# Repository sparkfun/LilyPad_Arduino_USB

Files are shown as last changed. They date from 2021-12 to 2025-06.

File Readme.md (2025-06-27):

LilyPad Arduino USB
===================

[LilyPad Arduino USB  
*LilyPad Arduino USB (DEV-11990)*](https://www.sparkfun.com/products/11190)

The LilyPad Arduino USB is a sewable Arduino compatible board with a built-in LiPo battery charger. It connects via microUSB cable to your computer, which means that, unlike regular LilyPad boards, it needs no external hardware to be programmed. 

As of Arduino release 1.0.2, the LilyPad Arduino USB is supported as a native board- no additional files needed!

Firmware was compiled in WinAVR-20100110.  
Hardware was developed in EAGLE 6.3.0.

License Information
-------------------
The hardware design is released under [CC-SA v3 license](http://creativecommons.org/licenses/by-sa/3.0/us/).

The firmware is released under a modified beerware license, allowing for the purchase of any libation, alcoholic or non.

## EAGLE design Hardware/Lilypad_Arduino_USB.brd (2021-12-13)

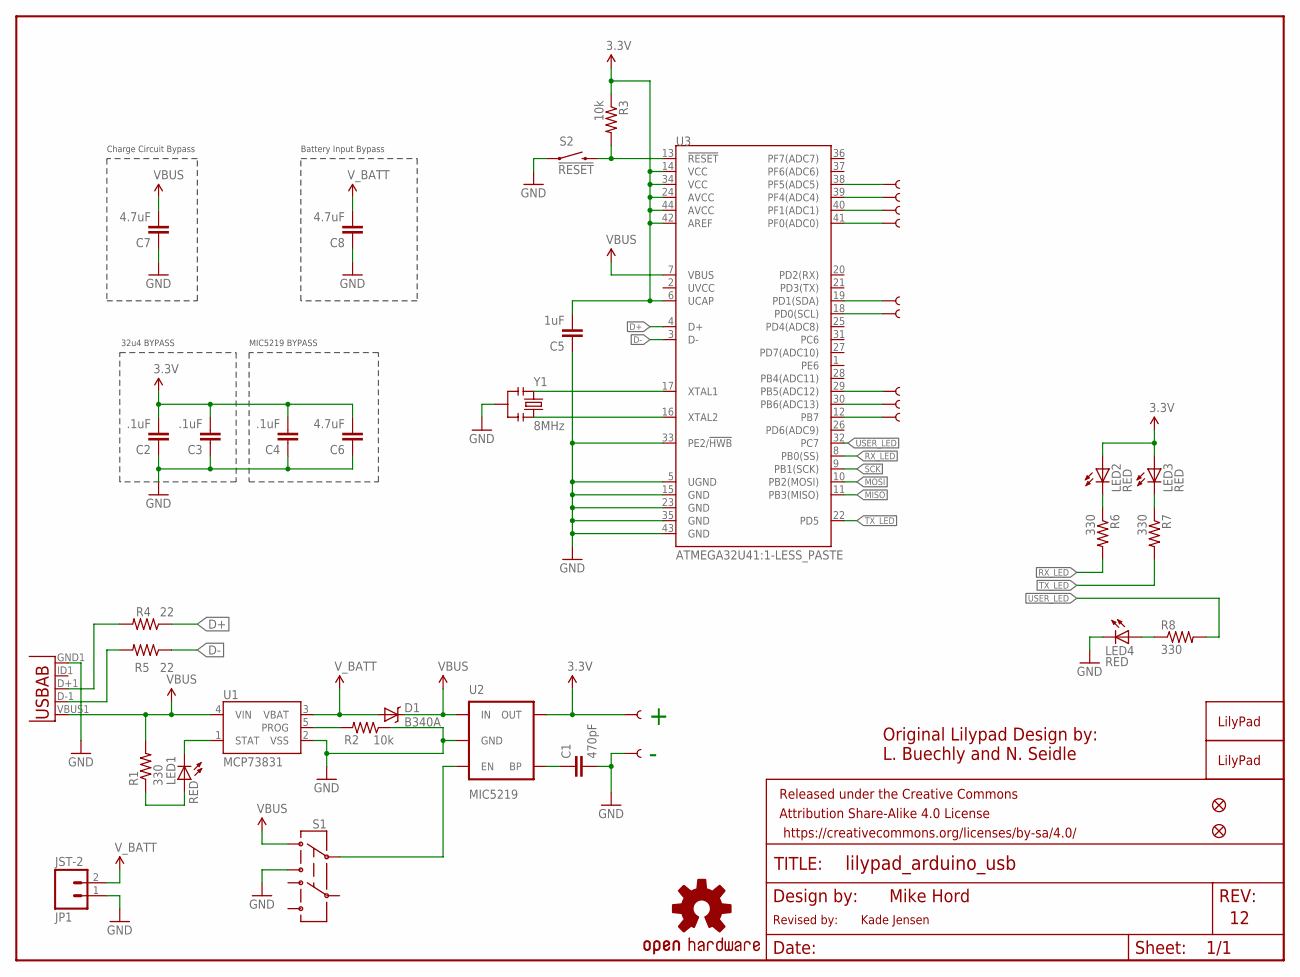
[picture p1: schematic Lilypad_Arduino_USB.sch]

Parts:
+: SEWTAP9; PETAL-LONG-1-2SIDE
-: SEWTAP9; PETAL-LONG-1-2SIDE
A2, A3, A4, A5: SEWTAP9; PETAL-LONG-1-2SIDE
C1: 470pF; 0603-CAP
C2, C3, C4: .1uF; 0603-CAP
C5: 1uF; 0603-CAP
C6: 4.7uF; 0603-CAP
C7, C8: 4.7uF; 1206
D1: B340A; SMA-DIODE
D5, D6, D9, D10, D11: SEWTAP9; PETAL-LONG-1-2SIDE
FRAME1: FRAME-LETTER; CREATIVE_COMMONS
JP1: JST-2; JST-2-SMD
JP2, JP3: FIDUCIAL1X2; FIDUCIAL-1X2
LED1, LED2, LED3, LED4: RED; LED-0603
R1, R6, R7, R8: 330; 0603-RES
R2, R3: 10k; 0603-RES
R4, R5: 22; 0603-RES
S1: SWITCH-DPDTAYZ0202; AYZ0202
S2: !RESET; TACTILE_SWITCH_SMD
U1: MCP73831; SOT23-5
U2: MIC5219; SOT23-5
U3: ATMEGA32U41:1-LESS_PASTE; QFN-44-NOPAD_1:1-LESS_PASTE
U5: USB-ABCONN-11794; USB-AB-MICRO-SMD_V03
U$1: LOGO-LPLPA; LOGO-LPA
U$5: OSHW-LOGOM; OSHW-LOGO-M
U$13: LOGO-LPLP; LOGO-LILYPAD
Y1: 8MHz; RESONATOR-SMD

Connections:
3.3V: +.1, C2.2, C3.2, C4.2, C5.2, C6.2, LED2.A, LED3.A, R3.1, U2.5 (OUT), U3.6 (UCAP), U3.14 (VCC), U3.24 (AVCC), U3.34 (VCC), U3.42 (AREF), U3.44 (AVCC)
5V: C7.2, D1.C, R1.2, S1.1, U1.4 (VIN), U2.1 (IN), U3.7 (VBUS), U5.VBUS1 (VBUS)
D+: R4.1, U3.4 (D+)
D-: R5.1, U3.3 (D-)
GND: -.1, C1.2, C2.1, C3.1, C4.1, C5.1, C6.1, C7.1, C8.1, JP1.1 (2), LED4.C, R2.1, S1.3, S2.1, U1.2 (VSS), U2.2 (GND), U3.5 (UGND), U3.15 (GND), U3.23 (GND), U3.33 (PE2/!HWB), U3.35 (GND), U3.43 (GND), U5.GND1 (GND), Y1.2
MISO: U3.11 (PB3(MISO))
MOSI: U3.10 (PB2(MOSI))
unnamed: LED2.C, R6.1
unnamed: S1.2, U2.3 (EN)
unnamed: LED1.A, R1.1
unnamed: LED1.C, U1.1 (STAT)
unnamed: U3.17 (XTAL1), Y1.1
unnamed: R2.2, U1.5 (PROG)
unnamed: U3.16 (XTAL2), Y1.3
unnamed: C1.1, U2.4 (BP)
unnamed: D11.1, U3.12 (PB7)
unnamed: D10.1, U3.30 (PB6(ADC13))
unnamed: D9.1, U3.29 (PB5(ADC12))
unnamed: D5.1, U3.19 (PD1(SDA))
unnamed: D6.1, U3.18 (PD0(SCL))
unnamed: A5.1, U3.41 (PF0(ADC0))
unnamed: A4.1, U3.40 (PF1(ADC1))
unnamed: A3.1, U3.39 (PF4(ADC4))
unnamed: A2.1, U3.38 (PF5(ADC5))
unnamed: LED4.A, R8.1
unnamed: R5.2, U5.D-1 (D-)
unnamed: R4.2, U5.D+1 (D+)
unnamed: LED3.C, R7.1
RESET: R3.2, S2.3 (2), U3.13 (!RESET)
RX_LED: R6.2, U3.8 (PB0(SS))
SCK: U3.9 (PB1(SCK))
TX_LED: R7.2, U3.22 (PD5)
USER_LED: R8.2, U3.32 (PC7)
V_BATT: C8.2, D1.A, JP1.2 (1), U1.3 (VBAT)

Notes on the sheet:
32u4 BYPASS
MIC5219 BYPASS
Mike Hord
Original Lilypad Design by:
L. Buechly and N. Seidle
Charge Circuit Bypass
Battery Input Bypass
Revised by:
Kade Jensen

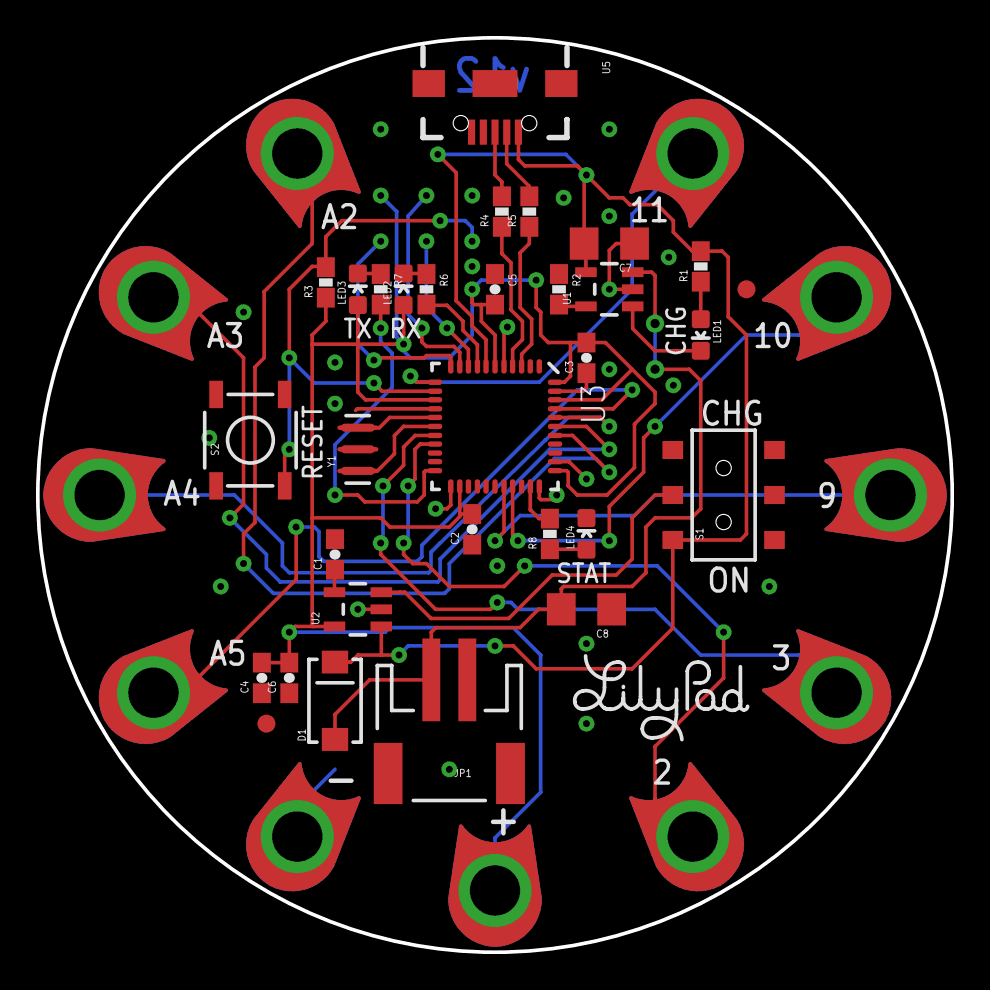
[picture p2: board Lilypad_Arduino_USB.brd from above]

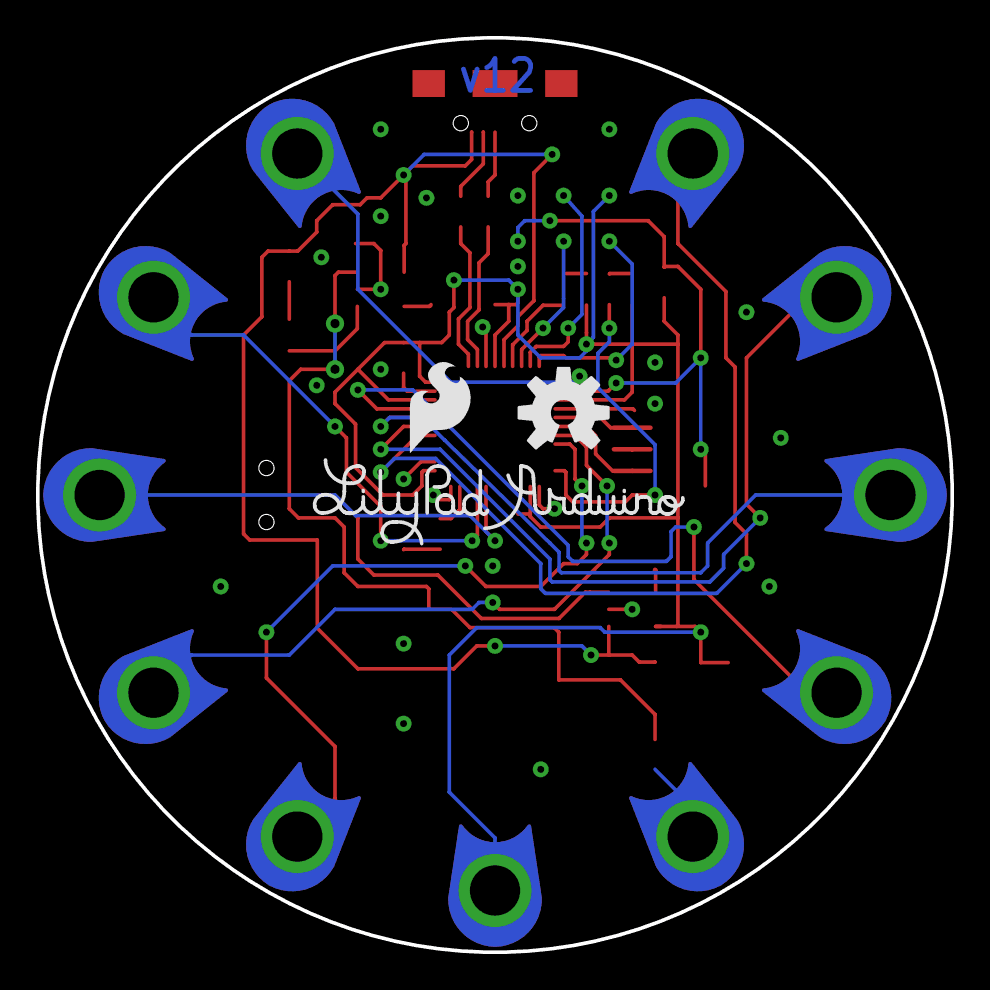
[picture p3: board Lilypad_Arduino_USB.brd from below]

Board: 2 copper layers, 50.8 x 50.8 mm, 47 parts (3 on the bottom side), 31 nets.

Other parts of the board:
U$7: SFE_LOGO_FLAME_.2

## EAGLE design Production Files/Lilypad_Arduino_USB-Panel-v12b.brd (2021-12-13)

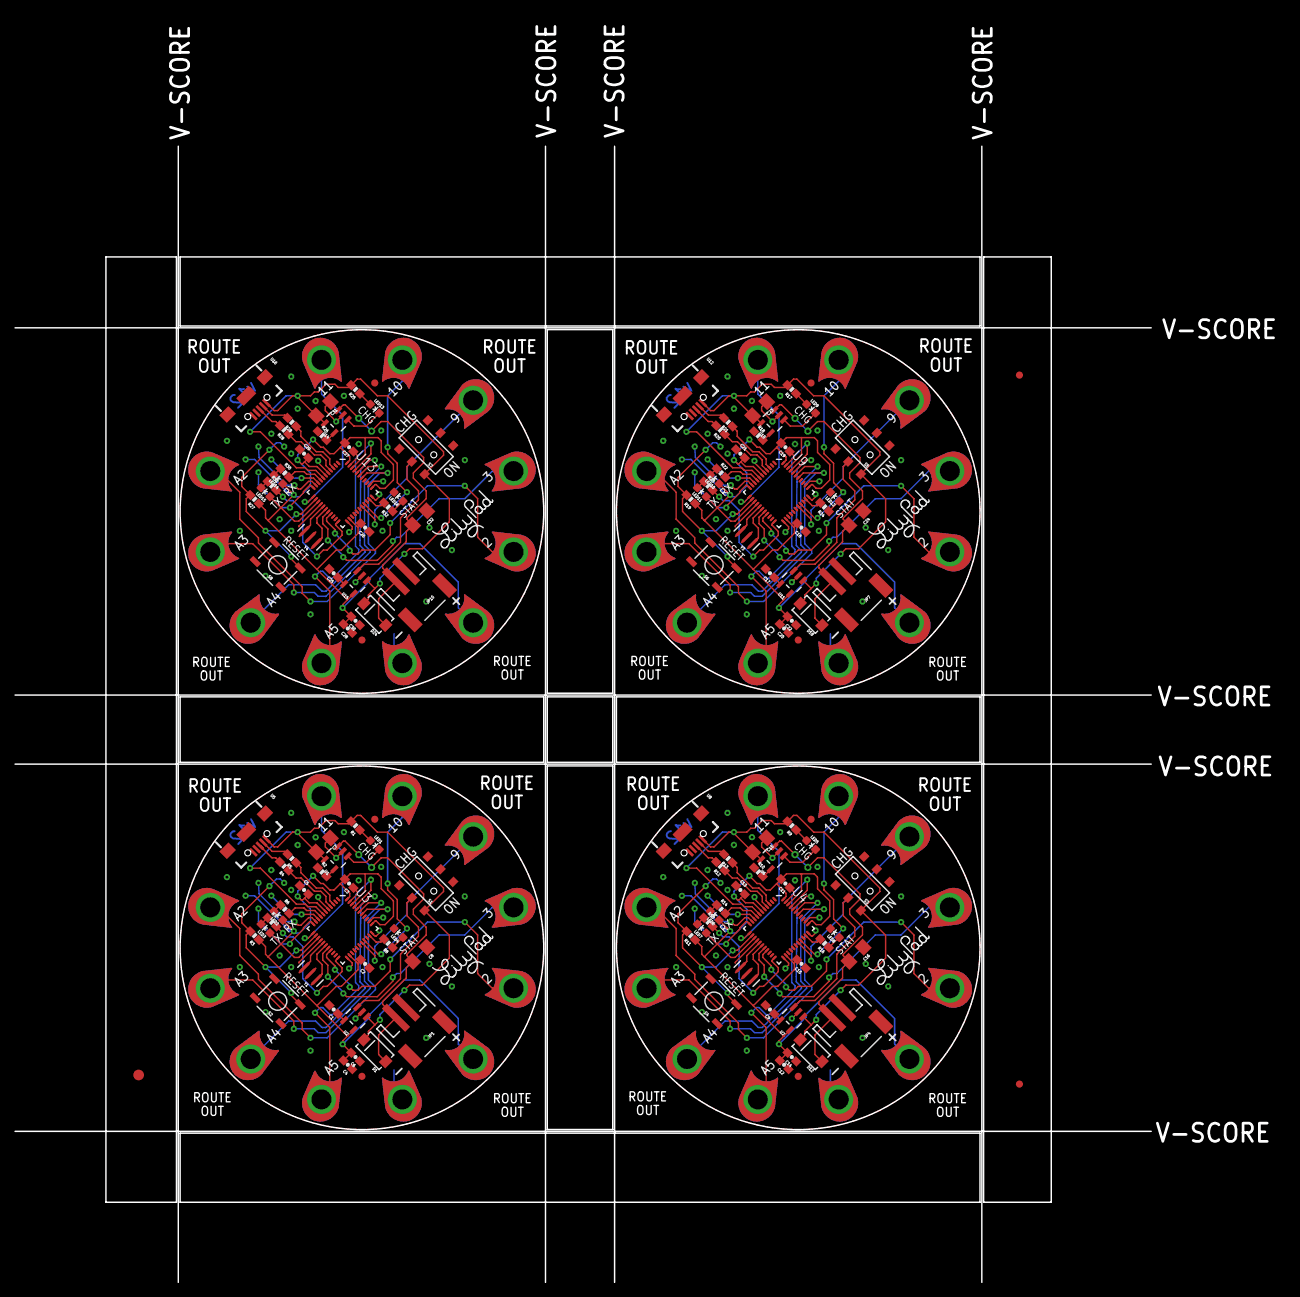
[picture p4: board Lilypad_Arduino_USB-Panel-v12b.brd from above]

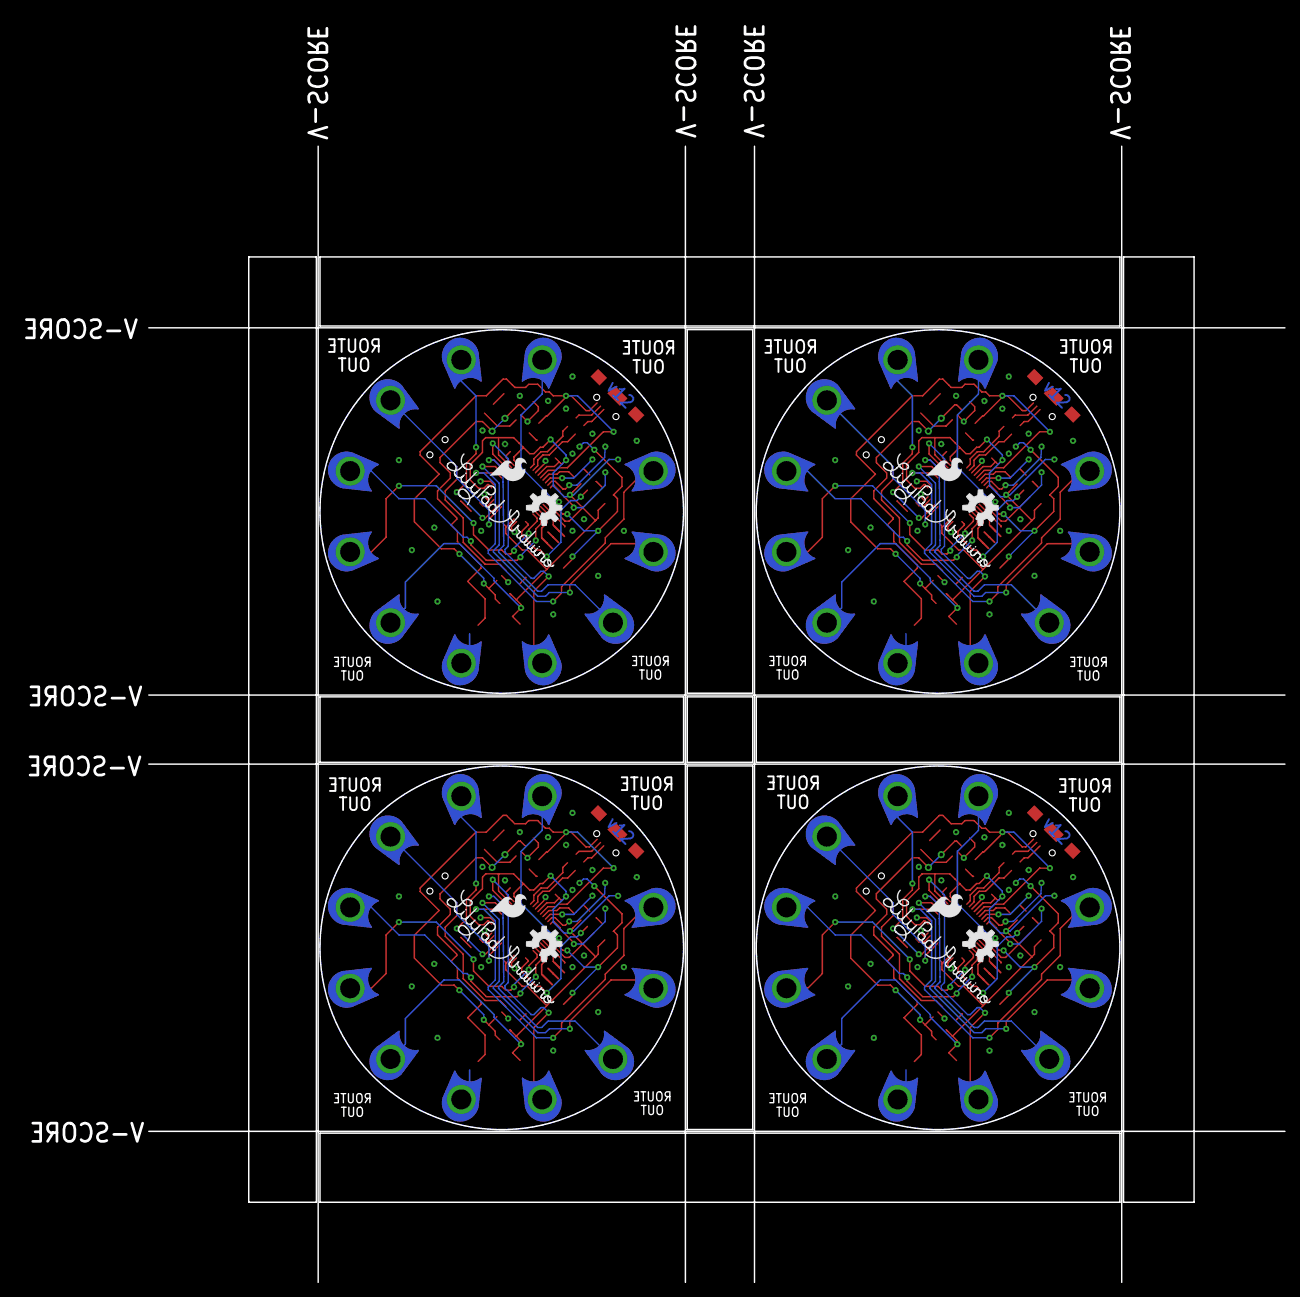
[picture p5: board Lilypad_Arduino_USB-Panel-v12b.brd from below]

Board: 2 copper layers, 158.8 x 158.8 mm, 187 parts (12 on the bottom side), 124 nets.

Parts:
+, +1, +2, +3: SEWTAP9; PETAL-LONG-1-2SIDE
-, -1, -2, -3: SEWTAP9; PETAL-LONG-1-2SIDE
A1, A2, A3, A4, A5, A6, A7, A8, A9, A10, A11, A12, A13, A14, A15, A16: SEWTAP9; PETAL-LONG-1-2SIDE
C1, C9, C17, C25: 470pF; 0603-CAP
C2, C3, C4, C10, C11, C12, C18, C19, C20, C26, C27, C28: .1uF; 0603-CAP
C5, C13, C21, C29: 1uF; 0603-CAP
C6, C14, C22, C30: 4.7uF; 0603-CAP
C7, C8, C15, C16, C23, C24, C31, C32: 4.7uF; 1206
D1, D12, D18, D24: B340A; SMA-DIODE
D2, D3, D4, D5, D6, D7, D8, D9, D10, D11, D13, D14, D15, D16, D17, D19, D20, D21, D22, D23: SEWTAP9; PETAL-LONG-1-2SIDE
E$1: FIDUCIAL-1.5X3
E$3, E$5: FIDUCIAL-1X2
JP1, JP4, JP7, JP10: JST-2; JST-2-SMD
JP2, JP3, JP5, JP6, JP8, JP9, JP11, JP12: FIDUCIAL1X2; FIDUCIAL-1X2
LED1, LED2, LED3, LED4, LED5, LED6, LED7, LED8, LED9, LED10, LED11, LED12, LED13, LED14, LED15, LED16: RED; LED-0603
R1, R6, R7, R8, R9, R14, R15, R16, R17, R22, R23, R24, R25, R30, R31, R32: 330; 0603-RES
R2, R3, R10, R11, R18, R19, R26, R27: 10k; 0603-RES
R4, R5, R12, R13, R20, R21, R28, R29: 22; 0603-RES
S1, S3, S5, S7: AYZ0202
S2, S4, S6, S8: !RESET; TACTILE_SWITCH_SMD
U1, U6, U10, U14: MCP73831; SOT23-5
U2, U7, U11, U15: MIC5219; SOT23-5
U3, U4, U9, U13: ATMEGA32U41:1-LESS_PASTE; QFN-44-NOPAD_1:1-LESS_PASTE
U5, U8, U12, U16: USB-AB-MICRO-SMD_V03
U$1, U$3, U$9, U$14: LOGO-LPLPA; LOGO-LPA
U$2, U$8, U$12, U$13: LOGO-LPLP; LOGO-LILYPAD
U$4, U$5, U$10, U$15: OSHW-LOGOM; OSHW-LOGO-M
U$6, U$7, U$11, U$16: SFE_LOGO_FLAME_.2
Y1, Y2, Y3, Y4: 8MHz; RESONATOR-SMD

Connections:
3.3V: +.1, C2.2, C3.2, C4.2, C5.2, C6.2, LED2.A, LED3.A, R3.1, U2.5, U3.6, U3.14, U3.24, U3.34, U3.42, U3.44
3.3V1: +1.1, C10.2, C11.2, C12.2, C13.2, C14.2, LED6.A, LED7.A, R11.1, U4.6, U4.14, U4.24, U4.34, U4.42, U4.44, U7.5
3.3V2: +2.1, C18.2, C19.2, C20.2, C21.2, C22.2, LED10.A, LED11.A, R19.1, U9.6, U9.14, U9.24, U9.34, U9.42, U9.44, U11.5
3.3V3: +3.1, C26.2, C27.2, C28.2, C29.2, C30.2, LED14.A, LED15.A, R27.1, U13.6, U13.14, U13.24, U13.34, U13.42, U13.44, U15.5
5V: C7.2, D1.C, R1.2, S1.1, U1.4, U2.1, U3.7, U5.VBUS1
5V1: C15.2, D12.C, R9.2, S3.1, U4.7, U6.4, U7.1, U8.VBUS1
5V2: C23.2, D18.C, R17.2, S5.1, U9.7, U10.4, U11.1, U12.VBUS1
5V3: C31.2, D24.C, R25.2, S7.1, U13.7, U14.4, U15.1, U16.VBUS1
D+: R4.1, U3.4
D+1: R12.1, U4.4
D+2: R20.1, U9.4
D+3: R28.1, U13.4
D-: R5.1, U3.3
D-1: R13.1, U4.3
D-2: R21.1, U9.3
D-3: R29.1, U13.3
GND: -.1, C1.2, C2.1, C3.1, C4.1, C5.1, C6.1, C7.1, C8.1, JP1.1, LED4.C, R2.1, S1.3, S2.1, U1.2, U2.2, U3.5, U3.15, U3.23, U3.33, U3.35, U3.43, U5.GND1, Y1.2
GND1: -1.1, C9.2, C10.1, C11.1, C12.1, C13.1, C14.1, C15.1, C16.1, JP4.1, LED8.C, R10.1, S3.3, S4.1, U4.5, U4.15, U4.23, U4.33, U4.35, U4.43, U6.2, U7.2, U8.GND1, Y2.2
GND2: -2.1, C17.2, C18.1, C19.1, C20.1, C21.1, C22.1, C23.1, C24.1, JP7.1, LED12.C, R18.1, S5.3, S6.1, U9.5, U9.15, U9.23, U9.33, U9.35, U9.43, U10.2, U11.2, U12.GND1, Y3.2
GND3: -3.1, C25.2, C26.1, C27.1, C28.1, C29.1, C30.1, C31.1, C32.1, JP10.1, LED16.C, R26.1, S7.3, S8.1, U13.5, U13.15, U13.23, U13.33, U13.35, U13.43, U14.2, U15.2, U16.GND1, Y4.2
unnamed: LED2.C, R6.1
unnamed: S1.2, U2.3
unnamed: LED1.A, R1.1
unnamed: LED1.C, U1.1
unnamed: U3.17, Y1.1
unnamed: R2.2, U1.5
unnamed: U3.16, Y1.3
unnamed: C1.1, U2.4
unnamed: D11.1, U3.12
unnamed: D10.1, U3.30
unnamed: D9.1, U3.29
unnamed: D5.1, U3.19
unnamed: D6.1, U3.18
unnamed: A5.1, U3.41
unnamed: A4.1, U3.40
unnamed: A3.1, U3.39
unnamed: A2.1, U3.38
unnamed: LED4.A, R8.1
unnamed: R5.2, U5.D-1
unnamed: R4.2, U5.D+1
unnamed: LED3.C, R7.1
unnamed: S3.2, U7.3
unnamed: LED5.A, R9.1
unnamed: LED5.C, U6.1
unnamed: R10.2, U6.5
unnamed: C9.1, U7.4
unnamed: D8.1, U4.12
unnamed: D7.1, U4.30
unnamed: D3.1, U4.29
unnamed: A7.1, U4.41
unnamed: A8.1, U4.40
unnamed: A6.1, U4.39
unnamed: A1.1, U4.38
unnamed: R13.2, U8.D-1
unnamed: R12.2, U8.D+1
unnamed: LED6.C, R14.1
unnamed: LED7.C, R15.1
unnamed: U4.17, Y2.1
unnamed: U4.16, Y2.3
unnamed: D2.1, U4.19
unnamed: D4.1, U4.18
unnamed: LED8.A, R16.1
unnamed: S5.2, U11.3
unnamed: LED9.A, R17.1
unnamed: LED9.C, U10.1
unnamed: R18.2, U10.5
unnamed: C17.1, U11.4
unnamed: D17.1, U9.12
unnamed: D16.1, U9.30
unnamed: D14.1, U9.29
unnamed: A11.1, U9.41
unnamed: A12.1, U9.40
unnamed: A10.1, U9.39
unnamed: A9.1, U9.38
unnamed: R21.2, U12.D-1
unnamed: R20.2, U12.D+1
unnamed: LED10.C, R22.1
unnamed: LED11.C, R23.1
unnamed: U9.17, Y3.1
unnamed: U9.16, Y3.3
unnamed: D13.1, U9.19
unnamed: D15.1, U9.18
unnamed: LED12.A, R24.1
unnamed: S7.2, U15.3
unnamed: LED13.A, R25.1
unnamed: LED13.C, U14.1
unnamed: R26.2, U14.5
unnamed: C25.1, U15.4
unnamed: D23.1, U13.12
unnamed: D22.1, U13.30
unnamed: D20.1, U13.29
unnamed: A15.1, U13.41
unnamed: A16.1, U13.40
unnamed: A14.1, U13.39
unnamed: A13.1, U13.38
unnamed: R29.2, U16.D-1
unnamed: R28.2, U16.D+1
unnamed: LED14.C, R30.1
unnamed: LED15.C, R31.1
unnamed: U13.17, Y4.1
unnamed: U13.16, Y4.3
unnamed: D19.1, U13.19
unnamed: D21.1, U13.18
unnamed: LED16.A, R32.1
RESET: R3.2, S2.3, U3.13
RESET1: R11.2, S4.3, U4.13
RESET2: R19.2, S6.3, U9.13
RESET3: R27.2, S8.3, U13.13
RX_LED: R6.2, U3.8
RX_LED1: R14.2, U4.8
RX_LED2: R22.2, U9.8
RX_LED3: R30.2, U13.8
TX_LED: R7.2, U3.22
TX_LED1: R15.2, U4.22
TX_LED2: R23.2, U9.22
TX_LED3: R31.2, U13.22
USER_LED: R8.2, U3.32
USER_LED1: R16.2, U4.32
USER_LED2: R24.2, U9.32
USER_LED3: R32.2, U13.32
V_BATT: C8.2, D1.A, JP1.2, U1.3
V_BATT1: C16.2, D12.A, JP4.2, U6.3
V_BATT2: C24.2, D18.A, JP7.2, U10.3
V_BATT3: C32.2, D24.A, JP10.2, U14.3

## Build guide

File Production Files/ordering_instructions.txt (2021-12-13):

panel size, 131x131mm
PCB thickness, 0.8mm
number of layers, 2
soldermask color, Purple
silkscreen color, White
oz copper, 1oz
finish, HASL lead free
stencils, top
pcs per panel, 4
min trace width, 0.2000mm / 0.0080in
min drill size, 0.3810mm / 0.0150in

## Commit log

2012-12-10 Initial commit.
    This is the version of bootloader the shipped with
    the original LilyPad Arduino USB boards, and was released with
    Arduino IDE v1.0.2.
    This hardware is v10, and represents the initial shipping state of
    LilyPad Arduino USB boards.
    [Lilypad_Arduino_USB.brd, Lilypad_Arduino_USB.sch]
2012-12-10 Change micro USB connector to more robust package.
    [Lilypad_Arduino_USB.brd, Lilypad_Arduino_USB.sch]
2012-12-10 Panel for mass production
    Reoriented the board 45 degrees so that the USB connector doesn't hang
    over where production techs need to run the depanelizing blade along
    v-scores.
    [Lilypad_Arduino_USB_Panel-v11.brd]
2012-12-11 Moved the panelized file into a production directory to keep the customer-oriented files more tidy and less confusing.
    [Lilypad_Arduino_USB_Panel-v11.brd]
2012-12-13 Changed version number in both files.
    Masked via at .35, .275 to provide a test point for the charge circuit.
    Add USR mask on the user control LED to make it more clear what it does.
    Closes issues 1 and 2.
    [Lilypad_Arduino_USB.brd, Lilypad_Arduino_USB.sch]
2013-09-09 Quality Control Revision to PCB layout
    Changed:
    - Updated all 0402 footprints to 0603
    - Updated with new 1:1 footprint of 32u4 IC
    - Rerouted all traces straight away from IC
    - Added trestrict under IC to mitigate gnd plane
    - Moved crystal closer to IC
    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
    [Lilypad_Arduino_USB.brd, Lilypad_Arduino_USB.sch]
2013-10-04 Created Panel
    [Lilypad_Arduino_USB-Panel-v11.brd, Lilypad_Arduino_USB_Panel-v11.brd]
2013-10-04 Revert "Created Panel"
    This reverts commit 475b5a8a9a08da90b89791f5318257dca302304d.
    [Lilypad_Arduino_USB-Panel-v11.brd, Lilypad_Arduino_USB_Panel-v11.brd]
2013-10-04 Created Panel v12
    correct this time...
    [Lilypad_Arduino_USB-Panel-v12.brd, Lilypad_Arduino_USB_Panel-v11.brd]
2013-10-07 Minor silk changes
    Moved A4 silk so it doesn't get cut off by the button pads. Added
    Sparkfun flames in bottom silk.
    [Lilypad_Arduino_USB.brd]
2013-10-07 Added silk to reset button
    Added silk to reset button
    [Lilypad_Arduino_USB.brd]
2013-10-07 Re-created Panel
    Re-created panel v12
    [Lilypad_Arduino_USB-Panel-v12.brd]
2013-11-15 Fixing D+ trace connection
    ID line on USB connector was routed to D+ on micro and D+ on USB
    connector was unrouted. Fixed now.
    [Lilypad_Arduino_USB.brd, Lilypad_Arduino_USB.sch]
2013-12-05 Minor Silk fixes
    Silk for "A4" and "STAT" was getting cut off. Moved slightly to fix.
    [Lilypad_Arduino_USB.brd]
2014-03-27 More updated packages
    1.) New 0603 LED packages
    2.) New resonator package
    3.) Moved reset button over to allow silk to be correct size.
    4.) Added attribution to board file
    5.) Minor trace reroutes for new packages
    6.) New 32u4 package variant that changes paste layer.
    [Lilypad_Arduino_USB.brd, Lilypad_Arduino_USB.sch]
2014-04-07 Fixing wonky trace under C1
    Correcting a trace overshoot on C1 near vreg.
    [Lilypad_Arduino_USB.brd]
2014-04-21 Updated silk and two traces
    1.) Changed bottom silk to not interfere with vias
    2.) Changed two traces to be more efficient
    [Lilypad_Arduino_USB.brd]
2014-04-22 created panel v12
    [Lilypad_Arduino_USB-Panel-v12.brd]
2021-12-13 New production panel v12b - strength tabs and v-scores
    [Lilypad_Arduino_USB-Panel-v12b.GBL, Lilypad_Arduino_USB-Panel-v12b.GBO, Lilypad_Arduino_USB-Panel-v12b.GBP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]

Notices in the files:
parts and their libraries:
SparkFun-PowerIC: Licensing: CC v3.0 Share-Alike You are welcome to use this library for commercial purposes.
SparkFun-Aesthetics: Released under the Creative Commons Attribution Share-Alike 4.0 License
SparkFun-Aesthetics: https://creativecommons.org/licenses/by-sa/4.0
